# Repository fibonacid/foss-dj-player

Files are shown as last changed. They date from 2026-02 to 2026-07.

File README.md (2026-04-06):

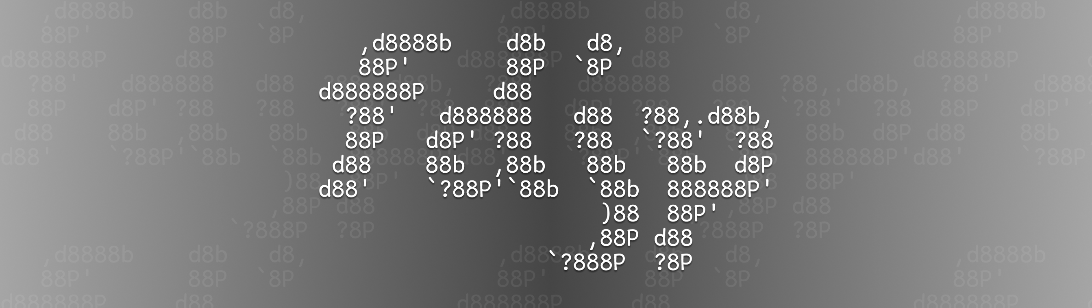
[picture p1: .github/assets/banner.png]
FOSS DJ PLAYER


<p align="center">
  <br/>
  DJ Players are over expensive and closed source. Let's fix it!
  <br/>
</p>

<div align="center">




</div>

Refer to the [docs](https://docs.foss-dj-player.org)

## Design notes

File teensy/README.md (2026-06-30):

# Firmware

## Sensor's list

So far we selected some sensors to tesst a possible layout of I/O we'd like to include. These are the sensors directly read by the teensy (few others directly interface with the raspberry pi).

- [ ] 1 1000PR jog wheel encoder [Exlimb E6B2-CWZ1X Incremental Rotary Encoder](https://it.aliexpress.com/item/1005006632253177.html).
- [ ] 1 track selection encoder [KY-040 360° rotary encoder module](https://it.aliexpress.com/item/1005010541982030.html)
- [x] 1 fader linear potentiometer [B10K 130 mm](https://it.aliexpress.com/item/1005006848969427.html)
- [x] buttons (16 buttons, pull-up resistor integrated into teensy)
    - 1 play
    - 1 cue
    - 5 hot cue
    - 1 master tempo
    - 3 loop (start, end, exit)
    - 1 fader scale
    - 2 next/prev track
    - 2 skip ahead/back
- [x] leds (3 leds)
    - 1 play
    - 1 cue
    - 2 loop active (to be integrated with loop start/end button)

## Libraries

- [bounce2](https://github.com/thomasfre) to implement automatic debouncing. 
- USBmidi is native and included in the .ini

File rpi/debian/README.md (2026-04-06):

# pi-gen

Tool used to create Raspberry Pi OS images, and custom images based on Raspberry Pi OS,
which was in turn derived from the Raspbian project.

**Note**: Raspberry Pi OS 32 bit images are based primarily on Raspbian, while
Raspberry Pi OS 64 bit images are based primarily on Debian.

**Note**: 32 bit images should be built from the `master` branch.
64 bit images should be built from the `arm64` branch.

## Dependencies

pi-gen runs on Debian-based operating systems released after 2017, and we
always advise you use the latest OS for security reasons.

On other Linux distributions it may be possible to use the Docker build described
below.

To install the required dependencies for `pi-gen` you should run:

```bash
apt install coreutils quilt parted qemu-user-static debootstrap zerofree zip \
dosfstools e2fsprogs libarchive-tools libcap2-bin grep rsync xz-utils file git curl bc \
gpg pigz xxd arch-test bmap-tools kmod
```

The file `depends` contains a list of tools needed. The format of this
package is `<tool>[:<debian-package>]`.

## Getting started with building your images

Getting started is as simple as cloning this repository on your build machine. You
can do so with:

```bash
git clone https://github.com/RPI-Distro/pi-gen.git
```

`--depth 1` can be added after `git clone` to create a shallow clone, only containing
the latest revision of the repository. Do not do this on your development machine.

Also, be careful to clone the repository to a base path **NOT** containing spaces.
This configuration is not supported by debootstrap and will lead to `pi-gen` not
running.

After cloning the repository, you can move to the next step and start configuring
your build.

## Config

Upon execution, `build.sh` will source the file `config` in the current
working directory. This bash shell fragment is intended to set needed
environment variables.

The following environment variables are supported:

- `IMG_NAME` (Default: `raspios-$RELEASE-$ARCH`, for example: `raspios-trixie-armhf`)

  The name of the image to build with the current stage directories. Use this
  variable to set the root name of your OS, eg `IMG_NAME=Frobulator`.
  Export files in stages may add suffixes to `IMG_NAME`.

- `PI_GEN_RELEASE` (Default: `Raspberry Pi reference`)

  The release name to use in `/etc/issue.txt`. The default should only be used
  for official Raspberry Pi builds.

- `RELEASE` (Default: `trixie`)

  The release version to build images against. Valid values are any supported
  Debian release. However, since different releases will have different sets of
  packages available, you'll need to either modify your stages accordingly, or
  checkout the appropriate branch. For example, if you'd like to build a
  `bullseye` image, you should do so from the `bullseye` branch.

- `APT_PROXY` (Default: unset)

  If you require the use of an apt proxy, set it here. This proxy setting
  will not be included in the image, making it safe to use an `apt-cacher` or
  similar package for development.

- `TEMP_REPO` (Default: unset)

  An additional temporary apt repo to be used during the build process. This
  could be useful if you require pre-release software to be included in the
  image. The variable should contain sources in [one-line-style format](https://manpages.debian.org/stable/apt/sources.list.5.en.html#ONE-LINE-STYLE_FORMAT).
  "RELEASE" will be replaced with the RELEASE variable.

- `BASE_DIR` (Default: location of `build.sh`)

  **CAUTION**: Currently, changing this value will probably break build.sh

  Top-level directory for `pi-gen`. Contains stage directories, build
  scripts, and by default both work and deployment directories.

- `WORK_DIR` (Default: `$BASE_DIR/work`)

  Directory in which `pi-gen` builds the target system. This value can be
  changed if you have a suitably large, fast storage location for stages to
  be built and cached. Note, `WORK_DIR` stores a complete copy of the target
  system for each build stage, amounting to tens of gigabytes in the case of
  Raspbian.

  **CAUTION**: If your working directory is on an NTFS partition you probably won't be able to build: make sure this is a proper Linux filesystem.

- `DEPLOY_DIR` (Default: `$BASE_DIR/deploy`)

  Output directory for target system images and NOOBS bundles.

- `DEPLOY_COMPRESSION` (Default: `zip`)

  Set to:
  - `none` to deploy the actual image (`.img`).
  - `zip` to deploy a zipped image (`.zip`).
  - `gz` to deploy a gzipped image (`.img.gz`).
  - `xz` to deploy a xzipped image (`.img.xz`).

- `DEPLOY_ZIP` (Deprecated)

  This option has been deprecated in favor of `DEPLOY_COMPRESSION`.

  If `DEPLOY_ZIP=0` is still present in your config file, the behavior is the
  same as with `DEPLOY_COMPRESSION=none`.

- `COMPRESSION_LEVEL` (Default: `6`)

  Compression level to be used when using `zip`, `gz` or `xz` for
  `DEPLOY_COMPRESSION`. From 0 to 9 (refer to the tool man page for more
  information on this. Usually 0 is no compression but very fast, up to 9 with
  the best compression but very slow ).

- `USE_QEMU` (Default: `0`)

  Setting to '1' enables the QEMU mode - creating an image that can be mounted via QEMU for an emulated
  environment. These images include "-qemu" in the image file name.

- `LOCALE_DEFAULT` (Default: 'en_GB.UTF-8' )

  Default system locale.

- `TARGET_HOSTNAME` (Default: 'raspberrypi' )

  Setting the hostname to the specified value.

- `KEYBOARD_KEYMAP` (Default: 'gb' )

  Default keyboard keymap.

  To get the current value from a running system, run `debconf-show
keyboard-configuration` and look at the
  `keyboard-configuration/xkb-keymap` value.

- `KEYBOARD_LAYOUT` (Default: 'English (UK)' )

  Default keyboard layout.

  To get the current value from a running system, run `debconf-show
keyboard-configuration` and look at the
  `keyboard-configuration/variant` value.

- `TIMEZONE_DEFAULT` (Default: 'Europe/London' )

  Default time zone.

  To get the current value from a running system, look in
  `/etc/timezone`.

- `FIRST_USER_NAME` (Default: `pi`)

  Username for the first user. This user only exists during the image creation process. Unless
  `DISABLE_FIRST_BOOT_USER_RENAME` is set to `1`, this user will be renamed on the first boot with
  a name chosen by the final user. This security feature is designed to prevent shipping images
  with a default username and help prevent malicious actors from taking over your devices.

  If the FIRST_USER_NAME is set to `pi` and no `FIRST_USER_PASS` is set, the setup wizard will be launched on first boot to allow the user to set the password.

- `FIRST_USER_PASS` (Default: unset)

  Password for the first user. If unset, the account is locked.

- `DISABLE_FIRST_BOOT_USER_RENAME` (Default: `0`)

  Disable the renaming of the first user during the first boot. This make it so `FIRST_USER_NAME`
  stays activated. `FIRST_USER_PASS` must be set for this to work. Please be aware of the implied
  security risk of defining a default username and password for your devices.

- `WPA_COUNTRY` (Default: unset)

  Sets the default WLAN regulatory domain and unblocks WLAN interfaces. This should be a 2-letter ISO/IEC 3166 country Code, i.e. `GB`

- `ENABLE_SSH` (Default: `0`)

  Setting to `1` will enable ssh server for remote log in. Note that if you are using a common password such as the defaults there is a high risk of attackers taking over you Raspberry Pi.

- `PUBKEY_SSH_FIRST_USER` (Default: unset)

Setting this to a value will make that value the contents of the FIRST_USER_NAME's ~/.ssh/authorized_keys. Obviously the value should
therefore be a valid authorized_keys file. Note that this does not
automatically enable SSH.

- `PUBKEY_ONLY_SSH` (Default: `0`)

- Setting to `1` will disable password authentication for SSH and enable
  public key authentication. Note that if SSH is not enabled this will take
  effect when SSH becomes enabled.

- `SETFCAP` (Default: unset)
  - Setting to `1` will prevent pi-gen from dropping the "capabilities"
    feature. Generating the root filesystem with capabilities enabled and running
    it from a filesystem that does not support capabilities (like NFS) can cause
    issues. Only enable this if you understand what it is.

- `STAGE_LIST` (Default: `stage*`)

  If set, then instead of working through the numeric stages in order, this list will be followed. For example setting to `"stage0 stage1 mystage stage2"` will run the contents of `mystage` before stage2. Note that quotes are needed around the list. An absolute or relative path can be given for stages outside the pi-gen directory.

- `EXPORT_CONFIG_DIR` (Default: `$BASE_DIR/export-image`)

  If set, use this directory path as the location of scripts to run when generating images. An absolute or relative path can be given for a location outside the pi-gen directory.

- `ENABLE_CLOUD_INIT` (Default: `1`)

  If set to `1`, cloud-init and netplan will be installed and configured. This will allow you to configure your Raspberry Pi using cloud-init configuration files. The cloud-init configuration files should be placed in the bootfs or by editing the files in `stage2/04-cloud-init/files`. Cloud-init will be configured to read them on first boot.

A simple example for building Raspberry Pi OS:

```bash
IMG_NAME='raspios'
```

The config file can also be specified on the command line as an argument the `build.sh` or `build-docker.sh` scripts.

```
./build.sh -c myconfig
```

This is parsed after `config` so can be used to override values set there.

## How the build process works

The following process is followed to build images:

- Iterate through all of the stage directories in alphanumeric order

- Bypass a stage directory if it contains a file called
  "SKIP"

- Run the script `prerun.sh` which is generally just used to copy the build
  directory between stages.

- In each stage directory iterate through each subdirectory and then run each of the
  install scripts it contains, again in alphanumeric order. **These need to be named
  with a two digit padded number at the beginning.**
  There are a number of different files and directories which can be used to
  control different parts of the build process:
  - **00-run.sh** - A unix shell script. Needs to be made executable for it to run.

  - **00-run-chroot.sh** - A unix shell script which will be run in the chroot
    of the image build directory. Needs to be made executable for it to run.

  - **00-debconf** - Contents of this file are passed to debconf-set-selections
    to configure things like locale, etc.

  - **00-packages** - A list of packages to install. Can have more than one, space
    separated, per line.

  - **00-packages-nr** - As 00-packages, except these will be installed using
    the `--no-install-recommends -y` parameters to apt-get.

  - **00-patches** - A directory containing patch files to be applied, using quilt.
    If a file named 'EDIT' is present in the directory, the build process will
    be interrupted with a bash session, allowing an opportunity to create/revise
    the patches.

- If the stage directory contains files called "EXPORT_NOOBS" or "EXPORT_IMAGE" then
  add this stage to a list of images to generate

- Generate the images for any stages that have specified them

It is recommended to examine build.sh for finer details.

## Docker Build

Docker can be used to perform the build inside a container. This partially isolates
the build from the host system, and allows using the script on non-debian based
systems (e.g. Fedora Linux). The isolation is not complete due to the need to use
some kernel level services for arm emulation (binfmt) and loop devices (losetup).

To build:

```bash
vi config         # Edit your config file. See above.
./build-docker.sh
```

If everything goes well, your finished image will be in the `deploy/` folder.
You can then remove the build container with `docker rm -v pigen_work`

If you encounter errors during the build, you can edit the corresponding scripts, and
continue:

```bash
CONTINUE=1 ./build-docker.sh
```

To examine the container after a failure you can enter a shell within it using:

```bash
sudo docker run -it --privileged --volumes-from=pigen_work pi-gen /bin/bash
```

After successful build, the build container is by default removed. This may be undesired when making incremental changes to a customized build. To prevent the build script from remove the container add

```bash
PRESERVE_CONTAINER=1 ./build-docker.sh
```

There is a possibility that even when running from a docker container, the
installation of `qemu-user-static` will silently fail when building the image
because `binfmt-support` _must be enabled on the underlying kernel_. An easy
fix is to ensure `binfmt-support` is installed on the host machine before
starting the `./build-docker.sh` script (or using your own docker build
solution).

### Passing arguments to Docker

When the docker image is run various required command line arguments are provided. For example the system mounts the `/dev` directory to the `/dev` directory within the docker container. If other arguments are required they may be specified in the PIGEN_DOCKER_OPTS environment variable. For example setting `PIGEN_DOCKER_OPTS="--add-host foo:192.168.0.23"` will add '192.168.0.23 foo' to the `/etc/hosts` file in the container. The `--name`
and `--privileged` options are already set by the script and should not be redefined.

## Stage Anatomy

### Raspbian Stage Overview

The build of Raspbian is divided up into several stages for logical clarity
and modularity. This causes some initial complexity, but it simplifies
maintenance and allows for more easy customization.

- **Stage 0** - bootstrap. The primary purpose of this stage is to create a
  usable filesystem. This is accomplished largely through the use of
  `debootstrap`, which creates a minimal filesystem suitable for use as a
  base.tgz on Debian systems. This stage also configures apt settings and
  installs `raspberrypi-bootloader` which is missed by debootstrap. The
  minimal core is installed but not configured. As a result, this stage will not boot.

- **Stage 1** - truly minimal system. This stage makes the system bootable by
  installing system files like `/etc/fstab`, configures the bootloader, makes
  the network operable, and installs packages like raspi-config. At this
  stage the system should boot to a local console from which you have the
  means to perform basic tasks needed to configure and install the system.

- **Stage 2** - lite system. This stage produces the Raspberry Pi OS Lite image.
  Stage 2 installs some optimized memory functions, sets timezone and charmap
  defaults, installs fake-hwclock and ntp, wireless LAN and bluetooth support,
  dphys-swapfile, and other basics for managing the hardware. It also
  creates necessary groups and gives the pi user access to sudo and the
  standard console hardware permission groups.

  Note: Raspberry Pi OS Lite contains a number of tools for development,
  including `Python`, `Lua` and the `build-essential` package. If you are
  creating an image to deploy in products, be sure to remove extraneous development
  tools before deployment.

- **Stage 3** - desktop system. Here's where you get the full desktop system
  with X11 and LXDE, web browsers, git for development, Raspberry Pi OS custom UI
  enhancements, etc. This is a base desktop system, with some development
  tools installed.

- **Stage 4** - Normal Raspberry Pi OS image. System meant to fit on a 4GB card.
  This is the stage that installs most things that make Raspberry Pi OS friendly
  to new users - e.g. system documentation.

- **Stage 5** - The Raspberry Pi OS Full image. More development
  tools, an email client, learning tools like Scratch, specialized packages
  like sonic-pi, office productivity, etc.

### Stage specification

If you wish to build up to a specified stage (such as building up to stage 2
for a lite system), place an empty file named `SKIP` in each of the `./stage`
directories you wish not to include.

Then add an empty file named `SKIP_IMAGES` to `./stage4` and `./stage5` (if building up to stage 2) or
to `./stage2` (if building a minimal system).

```bash
# Example for building a lite system
echo "IMG_NAME='raspios'" > config
touch ./stage3/SKIP ./stage4/SKIP ./stage5/SKIP
touch ./stage4/SKIP_IMAGES ./stage5/SKIP_IMAGES
sudo ./build.sh  # or ./build-docker.sh
```

If you wish to build further configurations upon (for example) the lite
system, you can also delete the contents of `./stage3` and `./stage4` and
replace with your own contents in the same format.

## Skipping stages to speed up development

If you're working on a specific stage the recommended development process is as
follows:

- Add a file called SKIP*IMAGES into the directories containing EXPORT*\* files
  (currently stage2, stage4 and stage5)
- Add SKIP files to the stages you don't want to build. For example, if you're
  basing your image on the lite image you would add these to stages 3, 4 and 5.
- Run build.sh to build all stages
- Add SKIP files to the earlier successfully built stages
- Modify the last stage
- Rebuild just the last stage using `sudo CLEAN=1 ./build.sh` (or, for docker builds
  `PRESERVE_CONTAINER=1 CONTINUE=1 CLEAN=1 ./build-docker.sh`)
- Once you're happy with the image you can remove the SKIP_IMAGES files and
  export your image to test

# Troubleshooting

## `64 Bit Systems`

A 64 bit image can be generated from the `arm64` branch in this repository. Just
replace the command from [this section](#getting-started-with-building-your-images)
by the one below, and follow the rest of the documentation:

```bash
git clone --branch arm64 https://github.com/RPI-Distro/pi-gen.git
```

If you want to generate a 64 bits image from a Raspberry Pi running a 32 bits
version, you need to add `arm_64bit=1` to your `config.txt` file and reboot your
machine. This will restart your machine with a 64 bits kernel. This will only
work from a Raspberry Pi with a 64-bit capable processor (i.e. Raspberry Pi Zero
2, Raspberry Pi 3 or Raspberry Pi 4).

## `binfmt_misc`

Linux is able to execute binaries from other architectures, meaning that it should be
possible to make use of `pi-gen` on an x86_64 system, even though it will be running
ARM binaries. This requires support from the [`binfmt_misc`](https://en.wikipedia.org/wiki/Binfmt_misc)
kernel module.

You may see one of the following errors:

```
update-binfmts: warning: Couldn't load the binfmt_misc module.
```

```
W: Failure trying to run: chroot "/pi-gen/work/test/stage0/rootfs" /bin/true
and/or
chroot: failed to run command '/bin/true': Exec format error
```

To resolve this, ensure that the following files are available (install them if necessary):

```
/lib/modules/$(uname -r)/kernel/fs/binfmt_misc.ko
/usr/bin/qemu-aarch64-static
```

You may also need to load the module by hand - run `modprobe binfmt_misc`.

If you are using WSL to build you may have to enable the service `sudo update-binfmts --enable`

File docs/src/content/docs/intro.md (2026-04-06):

---
title: Introduction
---

## Product requirements

- must be [standalone](#standalone)
- must be [cheap](#cheap)
- must be [easy to assemble](#easy-to-assemble)
- must be [compatible with rekordbox USB sticks](#compatible-with-rekordbox-usb-sticks)
- must be [dj software agnostic](#dj-software-agnostic)

### Standalone

The player embeds the software and hardware required for playback, instead of relying of software on a separate device/computer
In simple terms: it's a player not a controller.

### Cheap

Pioneer has a monopoly that allows it to charge ridiculus amounts of money. This project aims to make DJ players affordable for the average person.
A good price point would be around the cost of a entry level DJ controller or a bit more.
The price should not get too close to the entry level DJ player for Pioneer (XDJ-700) which costs around 700 euros.

### Easy to Assemble

The player must be simple enough for someone with basic electronics skills to assemble it in a few hours or so.
The electronics connections should be done with a custom PCB
The PCB should include slots for external modules like microcontrollers and periferals
Soldering should be required but fairly easy, not too many components

### Compatible with rekordbox USB sticks

The Pioneer monopoly forces you to use rekordbox to store your media, cues etc.
Sadly we cannot ditch completely the pioneer ecosystem without making the alternative feel like a toy.
Thankfully, [mixxx](https://github.com/mixxxdj/mixxx) already supports this.

### DJ Software agnostic

The cool part about open source DJ players is that you own it completely. This means you can decide what kind of software should run on the player.
This means that the hardware is not tied to any specific DJ software.
You can flash a micro SD card with a custom linux ISO, including the DJ software pre-configured with Midi mappings and UI skins for the embedded touchscreen.

## How does it work

The FOSS dj player is build of several parts, which can be ordered and assembled using the resources provided in this repo.

| Component | Notes |
| --- | --- |
| 3D printed case | to hold everything together |
| Custom PCB | to hold the electronic connections without running cables al over the place |
| Buttons, Faders, Jog Wheel etc. | to interact with the player |
| MIDI controller module | to expose sensor input to the dj software as MIDI |
| Raspberry PI | to host the operating system and dj software + peripherals (usb, ethernet) |
| Audio DAC module | to output good quality audio from the raspberry pi + RCA connector output for mixers |
| Touch Screen Display | to interact with the dj software, and control some aspects with touch |
| 3D printed inserts | stuff to cover buttons, encoders etc. |

## Help needed

This project requires help in the following fields:

- Electronics
  - Designing PCBs
  - Finding components
  - Testing and Prototyping
- Software
  - Embedded development
  - Linux Ricing (debian)
- Product
  - Research on features and pricing
  - Industrial Design for 3D printing

If you want to help out in any way or simply provide feedback/support, join the [discord server](https://discord.gg/WABteAtQdq)

## References

- [XDJ100SX](https://github.com/marcmonka/XDJ100SX) Primary inspiration for this project
- [MIXXX](https://github.com/mixxxdj/mixxx) A FOSS DJ Software compatible with Linux

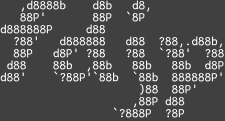
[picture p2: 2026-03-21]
design/brand/exports/fdjp/fdjp_dark_xs.png

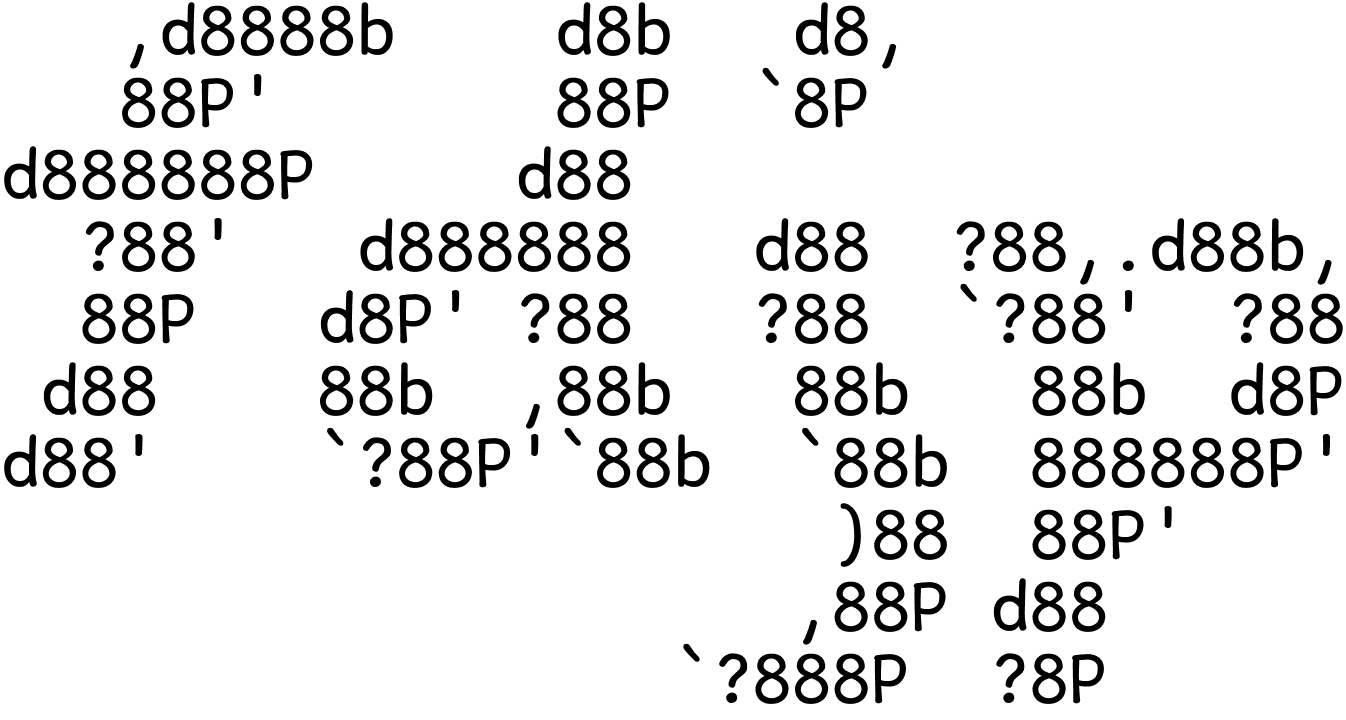
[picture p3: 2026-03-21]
design/brand/exports/fdjp/fdjp_light_7xl.png

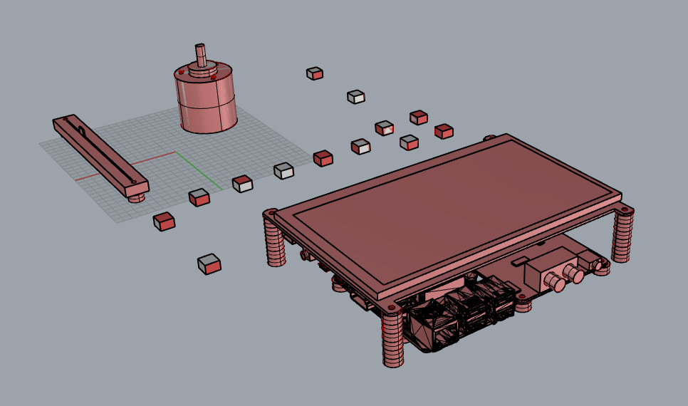
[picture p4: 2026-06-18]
design/cad/prototype-fede/ensemble.jpg

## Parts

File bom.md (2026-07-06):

# FOSS DJ Player — Bill of Materials

| ID  | Component | Manufacturer | Qty | Supplier | Notes |
| --- | --- | --- | --- | --- | --- |
| C1  | Rasperry PI 5 (RAM 8GB) | Raspberry Pi | 1 | [www.kubii.com](https://www.kubii.com/it/nano-computer/4106-raspberry-pi-5-3272496315938.html) (SKU: PI5) | 4GB version might work too |
| C2  | Power Supply Raspberry Pi USB-C 45W | | | [www.kubii.com](https://www.kubii.com/it/alimentatori/4658-2379-alimentazione-raspberry-pi-usb-c-45w-3272496323698.html) (SKU: PS-45W) | |
| C3  | DAC Audio IQaudio for Raspberry Pi (DAC+) | Raspberry Pi | 1 | [www.kubii.com](https://www.kubii.com/it/hat-dac-moduli/3181-dac-audio-iqaudio-per-raspberry-pi-3272496311565.html) | |
| C4  | Micro-SD Card (64 GB)" | Verbatim | | [www.kubii.com](https://www.kubii.com/it/supporti-di-archiviazione/3061-1479-scheda-micro-sd-verbatim-classe-10-3272496311527.html) (SKU: 44087_DEL) | |
| C5  | 7-inch capacitive LCD touch screen for Raspberry Pi | Waveshare | | [www.kubii.com](https://www.kubii.com/en/displays-supports/3789-7-inch-capacitive-lcd-touch-screen-for-raspberry-3272496312562.html) (SKU: WV14628)  | |
| C6  | Cooling fan for Raspberry Pi 5 | Rasberry Pi  | | [www.kubii.com](https://www.kubii.com/en/fans-heat-sinks/4109-cooling-fan-for-raspberry-pi-5-5056561803357.html) (SKU: SC1148) | |
| C7  | GPIO cable for Raspberry Pi | Kubii | | [www.kubii.com](https://www.kubii.com/en/hub-cables-adapters/426-gpio-cable-for-raspberry-pi-3272496001350.html) (SKU: KUB1988) | |
| E1  | Teensy 4.1 | PJRC | | [www.sparkfun.com](https://www.sparkfun.com/teensy-4-1-without-ethernet.html) (SKU: DEV-20359) | |

_Total components: 8_

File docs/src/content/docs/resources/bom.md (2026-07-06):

---
title: Bill of Materials
---

| ID  | Component | Manufacturer | Qty | Supplier | Notes |
| --- | --- | --- | --- | --- | --- |
| C1  | Rasperry PI 5 (RAM 8GB) | Raspberry Pi | 1 | [www.kubii.com](https://www.kubii.com/it/nano-computer/4106-raspberry-pi-5-3272496315938.html) (SKU: PI5) | 4GB version might work too |
| C2  | Power Supply Raspberry Pi USB-C 45W | Raspberry Pi | 1 | [www.kubii.com](https://www.kubii.com/it/alimentatori/4658-2379-alimentazione-raspberry-pi-usb-c-45w-3272496323698.html) (SKU: PS-45W) | |
| C3  | DAC Audio IQaudio for Raspberry Pi (DAC+) | Raspberry Pi | 1 | [www.kubii.com](https://www.kubii.com/it/hat-dac-moduli/3181-dac-audio-iqaudio-per-raspberry-pi-3272496311565.html) | |
| C4  | Micro-SD Card (64 GB)" | Verbatim | 1 | [www.kubii.com](https://www.kubii.com/it/supporti-di-archiviazione/3061-1479-scheda-micro-sd-verbatim-classe-10-3272496311527.html) (SKU: 44087_DEL) | |
| C5  | 7-inch capacitive LCD touch screen for Raspberry Pi | Waveshare | 1 | [www.kubii.com](https://www.kubii.com/en/displays-supports/3789-7-inch-capacitive-lcd-touch-screen-for-raspberry-3272496312562.html) (SKU: WV14628)  | |
| C6  | Cooling fan for Raspberry Pi 5 | Rasberry Pi  | 1 | [www.kubii.com](https://www.kubii.com/en/fans-heat-sinks/4109-cooling-fan-for-raspberry-pi-5-5056561803357.html) (SKU: SC1148) | |
| C7  | GPIO cable for Raspberry Pi | Kubii | 1 | [www.kubii.com](https://www.kubii.com/en/hub-cables-adapters/426-gpio-cable-for-raspberry-pi-3272496001350.html) (SKU: KUB1988) | |
| E1  | Teensy 4.1 | PJRC | 1 | [www.sparkfun.com](https://www.sparkfun.com/teensy-4-1-without-ethernet.html) (SKU: DEV-20359) | |

_Total components: 8_

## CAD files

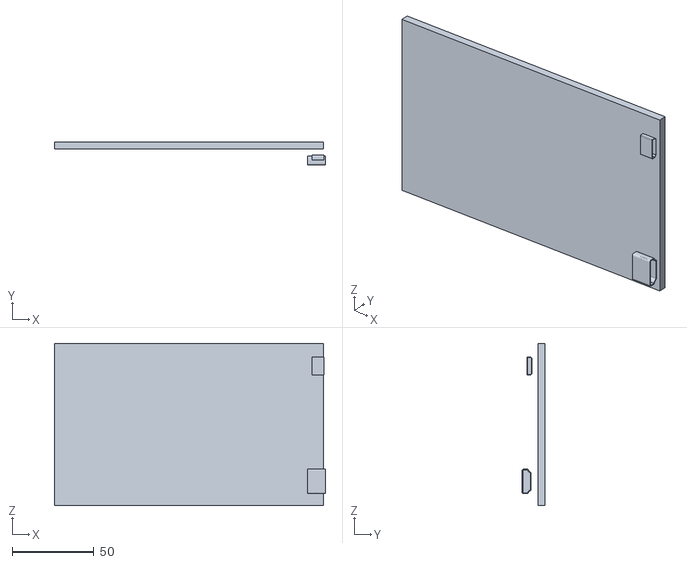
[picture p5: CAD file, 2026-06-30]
design/cad/_assets-digital-twins/lcd_panel.obj
165.4 x 14.0 x 99.0

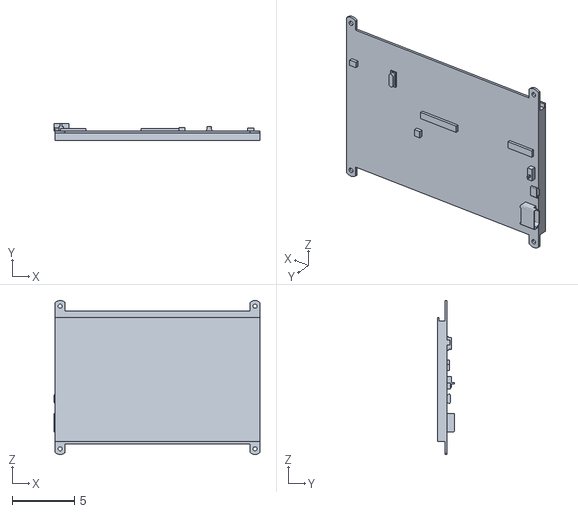
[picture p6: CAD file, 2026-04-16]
design/cad/_assets-generic/7inch_HDMI_LCD.obj
16.6 x 1.41 x 12.4

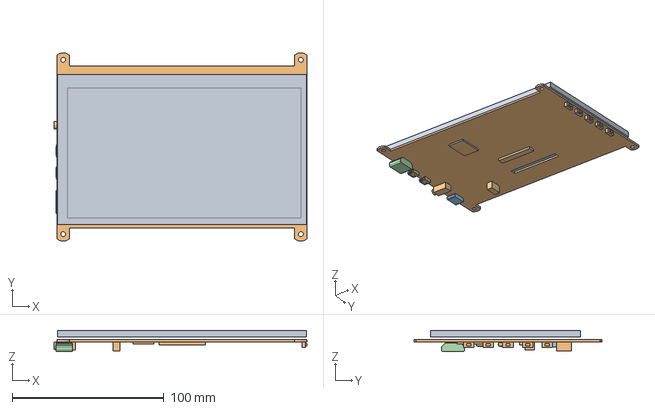
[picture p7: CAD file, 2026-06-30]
design/cad/_assets-generic/7inch_HDMI_LCD_(H)_drawing/f16-2.stp
167.0 x 124.3 x 14.0 mm

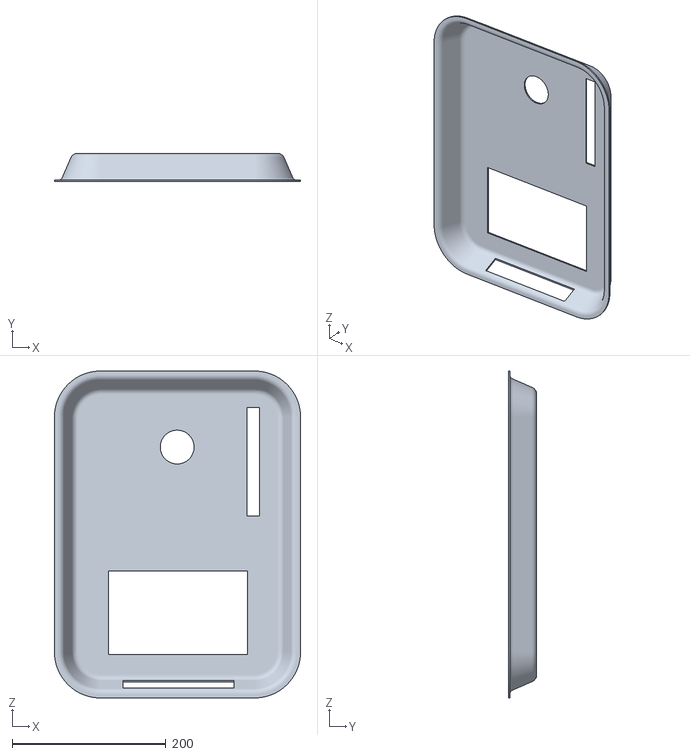
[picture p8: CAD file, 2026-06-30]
design/cad/_prototype/chassis.obj
320.0 x 37.0 x 425.0

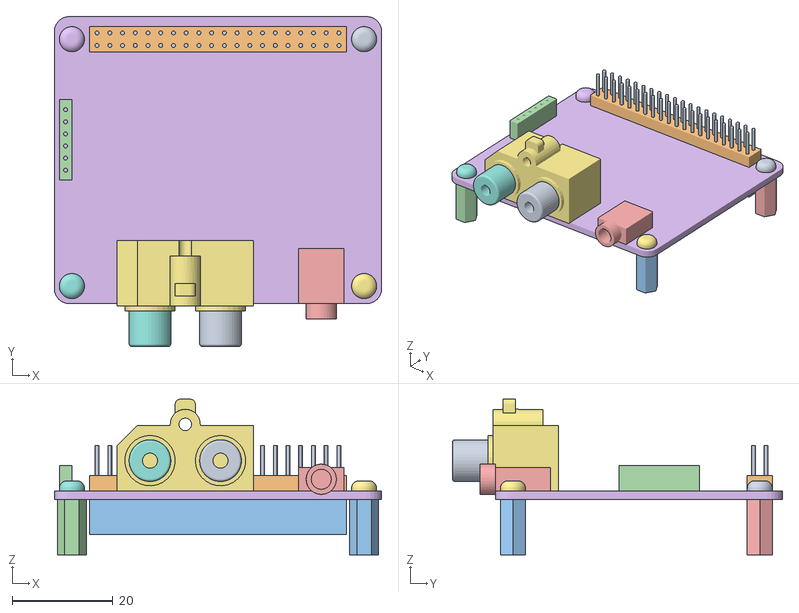
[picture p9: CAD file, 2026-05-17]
design/cad/dac.obj
65.0 x 65.5 x 30.9
Pins
Base
GPIO Socket
XLR Header
PCB

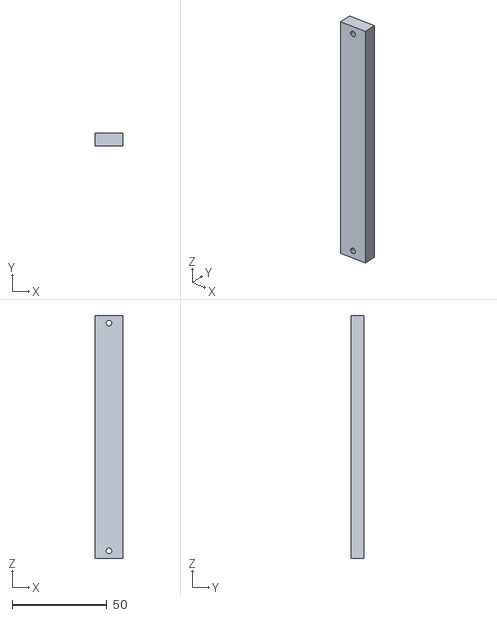
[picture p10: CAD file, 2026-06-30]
design/cad/_assets-digital-twins/potenziometro.obj
15.0 x 7.00 x 128.0

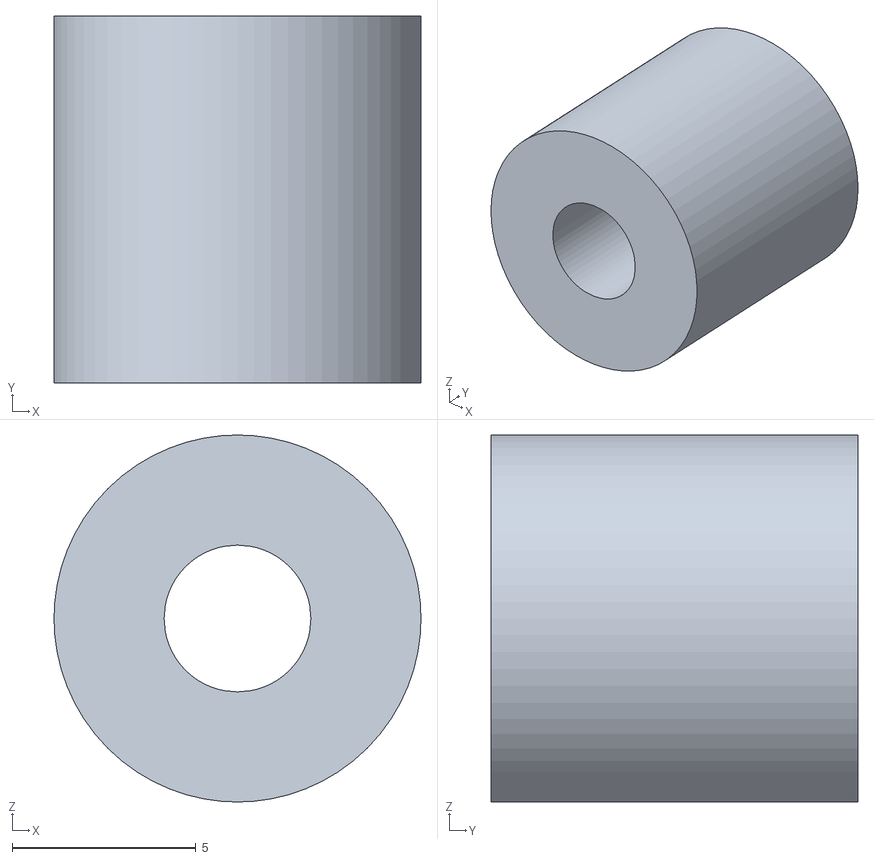
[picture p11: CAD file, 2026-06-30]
design/cad/_prototype/spacer.obj
10.0 x 10.0 x 10.0

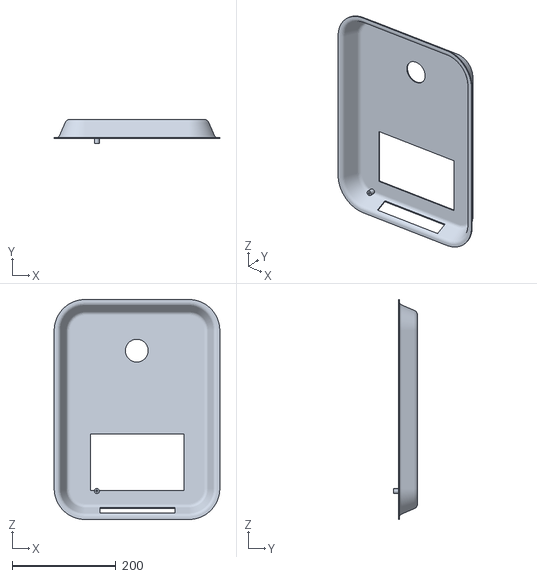
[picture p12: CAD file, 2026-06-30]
design/cad/_assets-digital-twins/spacer.obj
320.0 x 47.0 x 425.0

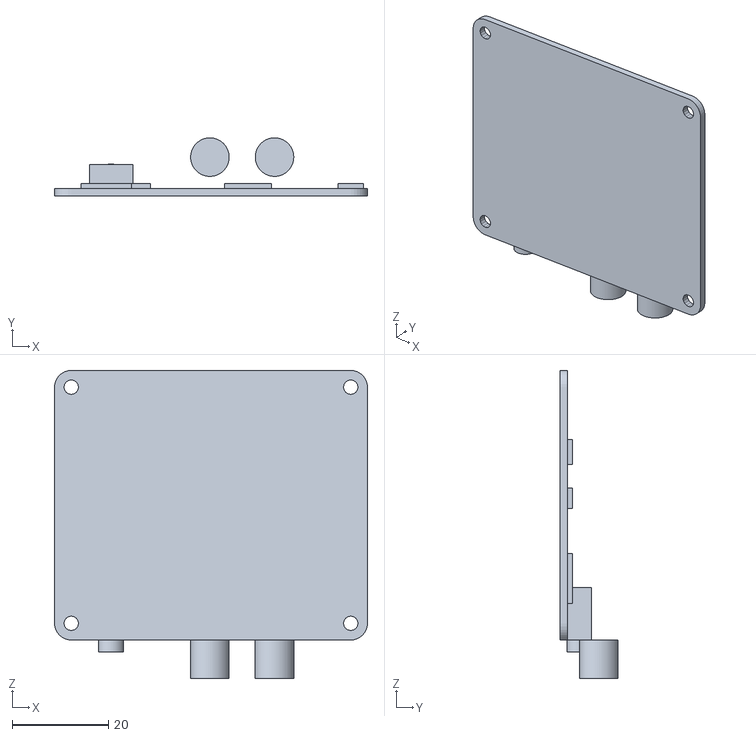
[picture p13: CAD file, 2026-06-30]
design/cad/_assets-digital-twins/pi_dac.obj
65.0 x 12.1 x 64.0

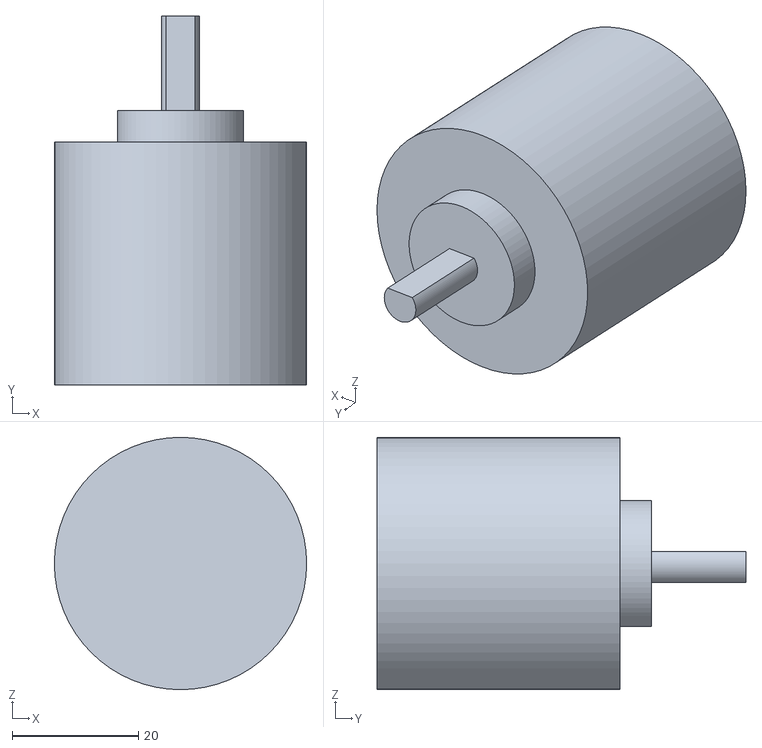
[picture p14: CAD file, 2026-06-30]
design/cad/_assets-digital-twins/rotary-encoder.obj
40.0 x 58.5 x 40.0

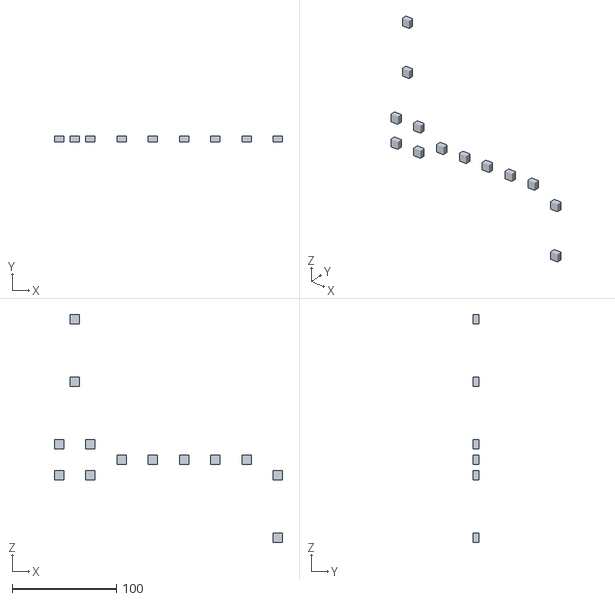
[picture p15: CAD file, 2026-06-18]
design/cad/_assets-digital-twins/buttons+enclosures.obj
219.0 x 6.00 x 219.0

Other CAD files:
design/cad/_assets-digital-twins/chassis.obj
design/cad/_assets-generic/7inch_HDMI_LCD_(H)_drawing/f16-2.dwg

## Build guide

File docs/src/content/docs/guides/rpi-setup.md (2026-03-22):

---
title: RPI Setup
description: Guide to prepare a Raspberry Pi with fdjp os image
---

## Prerequisites

### Hardware

- 1 Raspberry Pi 5 (8 gb recommended)
- 1 Waveshare 7 inch touch display
- 1 Raspberry Pi DAC Pro/+ Hat
- 1 microSD Card
- 1 GPIO ribbon cable

### Software

- Balena Etcher

## Preparing SD Card

Go to the [Releases](https://github.com/fibonacid/foss-dj-player/releases) page and scroll down until you see the _Assets_ list.
Click on the link for `foss-dj-player.zip` to download the disk image.
Open _Balena Etcher_ and insert microSD card into your computer to flash it with the file you just downloaded.
After flashing is done, remove the microSD card from your computer and put it in the Raspberry Pi.
When you turn on the RPI, you should expect the following:

1. splash screen with fjdp logo
2. tty screen with fdjp logo
3. mixxx opens automatically at fullscreen

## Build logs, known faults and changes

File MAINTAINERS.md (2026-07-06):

# Maintainers

This doc is for maintainers of this repo

## Node.js

Some aspect of the codebase are administered with Node.js.
To use node, the recommended approach is to download and install [nvm](https://github.com/nvm-sh/nvm)
After installing nvm, open a terminal in the repository root and run:

```bash
nvm use
corepack enable
corepack up
pnpm install
```

If everything is ok you can now run commands like these:

```bash
pnpm format
```

## Python

The script folder contains several python files that should be run with [uv](https://docs.astral.sh/uv/getting-started/installation/#standalone-installer)

```bash
# generate bom and put into public docs
pnpm scripts:bom
```

## Docker

To build RPI images we use docker. Install a recent version and refer to the `rpi` folder for details.

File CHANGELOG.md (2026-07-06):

# Changelog

## [0.1.6](https://github.com/fibonacid/foss-dj-player/compare/0.1.5...0.1.6) (2026-07-06)

### Bug Fixes

* **mixxx-controller:** add missing dev deps ([374c467](https://github.com/fibonacid/foss-dj-player/commit/374c46766ab9164773d413afb36cb1e53d61323b))
* **mixxx-controller:** correct controller class name ([8173c9d](https://github.com/fibonacid/foss-dj-player/commit/8173c9d597c72bdfcf93cf380559f0d67ad9180b))
* **mixxx-controller:** pin node and pnpm version ([bde6560](https://github.com/fibonacid/foss-dj-player/commit/bde656042b5d30fd3d20c4f422ca6224b974487e))

### Features

* **design:** add prototype cad files ([#31](https://github.com/fibonacid/foss-dj-player/issues/31)) ([54a9fd1](https://github.com/fibonacid/foss-dj-player/commit/54a9fd162045ca6d5f46cb2c5017688a25e04d49))
* **design:** modify foss-dj-player Grasshopper prototype ([#32](https://github.com/fibonacid/foss-dj-player/issues/32)) ([959edf2](https://github.com/fibonacid/foss-dj-player/commit/959edf2038ca3964d03e1f47ee02b83608ebf0ba))
* **firmware:** initial draft ([#30](https://github.com/fibonacid/foss-dj-player/issues/30)) ([fe4329b](https://github.com/fibonacid/foss-dj-player/commit/fe4329b4bfdf0a027fb77f74c9ce039c6e130e18))

## [0.1.5](https://github.com/fibonacid/foss-dj-player/compare/0.1.4...0.1.5) (2026-04-19)

### Features

* **alpine:** create alpine based rpi image ([#23](https://github.com/fibonacid/foss-dj-player/issues/23)) ([c0a0f6e](https://github.com/fibonacid/foss-dj-player/commit/c0a0f6e3263a293bda0a85c8ea99c6ba9b9d625e))
* **alpine:** export alpine img as zip ([a04e015](https://github.com/fibonacid/foss-dj-player/commit/a04e015954c5bd886dbe0de083595bb2d02cb2b9))
* **design:** export obj files from autodesk ([#24](https://github.com/fibonacid/foss-dj-player/issues/24)) ([541460f](https://github.com/fibonacid/foss-dj-player/commit/541460f5e53606a461512975381b36a2203a377f))
* **extra:** create mixxx controller xml and script ([#25](https://github.com/fibonacid/foss-dj-player/issues/25)) ([3c110b7](https://github.com/fibonacid/foss-dj-player/commit/3c110b7b21e6c93473bafef6a976ec9e4b0f53ab))
* **mixxx-controller:** add loop adjust mapping ([#27](https://github.com/fibonacid/foss-dj-player/issues/27)) ([859f768](https://github.com/fibonacid/foss-dj-player/commit/859f768139df5169981ef9a24c359677ffc3f3f9))

## [0.1.4](https://github.com/fibonacid/foss-dj-player/compare/0.1.3...0.1.4) (2026-04-06)

## [0.1.3](https://github.com/fibonacid/foss-dj-player/compare/0.1.2...0.1.3) (2026-03-22)

## [0.1.1](https://github.com/fibonacid/foss-dj-player/compare/0.1.0...0.1.1) (2026-03-08)

### Features

* **pi-gen:** add bootsplash image ([#13](https://github.com/fibonacid/foss-dj-player/issues/13)) ([14ae84f](https://github.com/fibonacid/foss-dj-player/commit/14ae84fec0b247044cb37747952364b43a7ae5f4))

# 0.1.0 (2026-02-28)

### Bug Fixes

* **pi-gen:** error in chown command ([b02b36c](https://github.com/fibonacid/foss-dj-player/commit/b02b36c7427b78380637a8bf087d7eba14a7ae9b))

### Features

* **pi-gen:** add autologin ([#3](https://github.com/fibonacid/foss-dj-player/issues/3)) ([99290bf](https://github.com/fibonacid/foss-dj-player/commit/99290bf9f07f665108c88a2e2c99f9eba583a153))
* **pi-gen:** add XDJ100SX skin ([14854aa](https://github.com/fibonacid/foss-dj-player/commit/14854aa2643efcf590b68af2a94f961a044e07e8))
* **pi-gen:** auto mount usb ([#2](https://github.com/fibonacid/foss-dj-player/issues/2)) ([15296db](https://github.com/fibonacid/foss-dj-player/commit/15296db7cc5e4931a4a36858f7f485b1994a2844))
* **pi-gen:** disable other libraries than rekordbox ([7b709c1](https://github.com/fibonacid/foss-dj-player/commit/7b709c1eccb8accb1d298b8e22e17e88fba4772e))
* **pi-gen:** seed mixxx config with XDJ100SX ([6151d7b](https://github.com/fibonacid/foss-dj-player/commit/6151d7b8c739be0abf23bc165696c4a49ad41eda))
* **pi-gen:** setup pi-gen ([5fe8b43](https://github.com/fibonacid/foss-dj-player/commit/5fe8b43f261de78647b036b66db9df736ae27f66))
* **pi-gen:** tiling window manager ([#4](https://github.com/fibonacid/foss-dj-player/issues/4)) ([a386c17](https://github.com/fibonacid/foss-dj-player/commit/a386c17458100540d397f9775a66ff7cb42af708))

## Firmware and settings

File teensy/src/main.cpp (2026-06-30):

#include <Arduino.h>
#include <Bounce2.h>
#include <Encoder.h>
#include "config.h"

Bounce butts[buttons::NUM_BUTTONS];
Encoder browse_enc(browse_encoder::BROWSE_ENC_A, browse_encoder::BROWSE_ENC_B);
Encoder jog(jogwheel::JOG_PIN_A, jogwheel::JOG_PIN_B);
Bounce browse_button = Bounce();
int last_fader = -1;
long old_jog_pos = 0;
unsigned long last_midi_time = 0;
const int update_interval = 10; // jogwheel update time in ms not to fill the buffer


// functions to handle leds
void note_on(byte channel, byte note, byte velocity) {
    for (int i = 0; i < leds::NUM_LEDS; i++) {
        if (note == leds::LED_NOTES[i]) {
            digitalWrite(leds::LED_PINS[i], velocity > 0 ? HIGH : LOW);
        }
    }
}

void note_off(byte channel, byte note, byte velocity) {
    for (int i = 0; i < leds::NUM_LEDS; i++) {
        if (note == leds::LED_NOTES[i]) {
            digitalWrite(leds::LED_PINS[i], LOW);
        }
    }
}



void setup() {

    // buttons
    for (int i = 0; i < buttons::NUM_BUTTONS; i++) {
        butts[i].attach(buttons::BUTTON_PINS[i], INPUT_PULLUP);
        butts[i].interval(buttons::DEBOUNCE_MS);
    }    

    // leds
    for (int i = 0; i < leds::NUM_LEDS; i++) {
        pinMode(leds::LED_PINS[i], OUTPUT); 
    }


    // browse encoder
    browse_button.attach(browse_encoder::BROWSE_BTN, INPUT_PULLUP);
    browse_button.interval(5);

    // callback for leds
    usbMIDI.setHandleNoteOn(note_on);
    usbMIDI.setHandleNoteOff(note_on);

}

void loop() {
    
    // read led event
    while (usbMIDI.read()) {}

    // buttons
    for (int i = 0; i < buttons::NUM_BUTTONS; i++) {    
        
        butts[i].update();
        
        if(butts[i].fell()) {
            usbMIDI.sendNoteOn(midi_config::NOTES[i], 127, midi_config::BUTTON_CHANNEL);
        }

        if(butts[i].rose()) {
            usbMIDI.sendNoteOff(midi_config::NOTES[i], 0, midi_config::BUTTON_CHANNEL);
        }

    }

    // fader
    int curr_fader = analogRead(fader::PIN) >> 3; // filter by cutting down 3 bits to 7 (128 pos)
    if (abs(curr_fader - last_fader) > fader::THRESH) { 
        usbMIDI.sendControlChange(midi_config::FADER_CC, curr_fader, 1);
        last_fader = curr_fader;
    }


    // browse encoder (rotation)
    static long oldBrowsePos = 0;
    long newBrowsePos = browse_enc.read() >> 2; // divide by 4 
    if (newBrowsePos != oldBrowsePos) {
        int delta = (newBrowsePos > oldBrowsePos) ? 65 : 63;
        usbMIDI.sendControlChange(browse_encoder::BROWSE_CC, delta, 1);
        oldBrowsePos = newBrowsePos;
    }

    // browse encoder (load track button)
    browse_button.update();
    if (browse_button.fell()) usbMIDI.sendNoteOn(browse_encoder::BROWSE_LOAD_NOTE, 127, 1);
    if (browse_button.rose()) usbMIDI.sendNoteOff(browse_encoder::BROWSE_LOAD_NOTE, 0, 1);

    // jogwheel encoder
    long new_jog_pos = jog.read();

    if (millis() - last_midi_time > update_interval) {
        if (new_jog_pos != old_jog_pos) {
            long diff = new_jog_pos - old_jog_pos;

            // 64 is 0. >64 forward, <64 backwards
            int delta;
            if (diff > 0) {
                delta = 64 + min((long)63, diff); // limit max jump
            } 
            else {
                delta = 64 - min((long)64, abs(diff));
            }

            usbMIDI.sendControlChange(jogwheel::JOG_CC, delta, jogwheel::MIDI_CH);
            
            old_jog_pos = new_jog_pos;
            last_midi_time = millis();
        }
    }



}

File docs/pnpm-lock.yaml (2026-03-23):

lockfileVersion: '9.0'

settings:
  autoInstallPeers: true
  excludeLinksFromLockfile: false

importers:

  .:
    dependencies:
      '@astrojs/starlight':
        specifier: ^0.38.1
        version: 0.38.1(astro@6.0.4(@types/node@24.12.0)(rollup@4.59.0))
      astro:
        specifier: ^6.0.1
        version: 6.0.4(@types/node@24.12.0)(rollup@4.59.0)
      astro-og-canvas:
        specifier: ^0.10.1
        version: 0.10.1(astro@6.0.4(@types/node@24.12.0)(rollup@4.59.0))
      canvaskit-wasm:
        specifier: ^0.41.0
        version: 0.41.0
      sharp:
        specifier: ^0.34.2
        version: 0.34.5

packages:

  '@astrojs/compiler@3.0.0':
    resolution: {integrity: sha512-MwAbDE5mawZ1SS+D8qWiHdprdME5Tlj2e0YjxnEICvcOpbSukNS7Sa7hA5PK+6RrmUr/t6Gi5YgrdZKjbO/WPQ==}

  '@astrojs/internal-helpers@0.8.0':
    resolution: {integrity: sha512-J56GrhEiV+4dmrGLPNOl2pZjpHXAndWVyiVDYGDuw6MWKpBSEMLdFxHzeM/6sqaknw9M+HFfHZAcvi3OfT3D/w==}

  '@astrojs/markdown-remark@7.0.0':
    resolution: {integrity: sha512-jTAXHPy45L7o1ljH4jYV+ShtOHtyQUa1mGp3a5fJp1soX8lInuTJQ6ihmldHzVM4Q7QptU4SzIDIcKbBJO7sXQ==}

  '@astrojs/mdx@5.0.0':
    resolution: {integrity: sha512-J4rW6eT+qgVw7+RXdBYO4vYyWGeXXQp8wop9dXsOlLzIsVSxyttMCgkGCWvIR2ogBqKqeYgI6YDW93PaDHkCaA==}
    engines: {node: ^20.19.1 || >=22.12.0}
    peerDependencies:
      astro: ^6.0.0-alpha.0

  '@astrojs/prism@4.0.0':
    resolution: {integrity: sha512-NndtNPpxaGinRpRytljGBvYHpTOwHycSZ/c+lQi5cHvkqqrHKWdkPEhImlODBNmbuB+vyQUNUDXyjzt66CihJg==}
    engines: {node: ^20.19.1 || >=22.12.0}

  '@astrojs/sitemap@3.7.1':
    resolution: {integrity: sha512-IzQqdTeskaMX+QDZCzMuJIp8A8C1vgzMBp/NmHNnadepHYNHcxQdGLQZYfkbd2EbRXUfOS+UDIKx8sKg0oWVdw==}

  '@astrojs/starlight@0.38.1':
    resolution: {integrity: sha512-CATPH4Dy44OYAJhoyUHh6NqpColWEVufanGVwnM0l/bcaNMo5V/rypwL0Vu0Edp+ZIXE7/1DA9CrNj5jmCVSLQ==}
    peerDependencies:
      astro: ^6.0.0

  '@astrojs/telemetry@3.3.0':
    resolution: {integrity: sha512-UFBgfeldP06qu6khs/yY+q1cDAaArM2/7AEIqQ9Cuvf7B1hNLq0xDrZkct+QoIGyjq56y8IaE2I3CTvG99mlhQ==}
    engines: {node: 18.20.8 || ^20.3.0 || >=22.0.0}

  '@babel/helper-string-parser@7.27.1':
    resolution: {integrity: sha512-qMlSxKbpRlAridDExk92nSobyDdpPijUq2DW6oDnUqd0iOGxmQjyqhMIihI9+zv4LPyZdRje2cavWPbCbWm3eA==}
    engines: {node: '>=6.9.0'}

  '@babel/helper-validator-identifier@7.28.5':
    resolution: {integrity: sha512-qSs4ifwzKJSV39ucNjsvc6WVHs6b7S03sOh2OcHF9UHfVPqWWALUsNUVzhSBiItjRZoLHx7nIarVjqKVusUZ1Q==}
    engines: {node: '>=6.9.0'}

  '@babel/parser@7.29.0':
    resolution: {integrity: sha512-IyDgFV5GeDUVX4YdF/3CPULtVGSXXMLh1xVIgdCgxApktqnQV0r7/8Nqthg+8YLGaAtdyIlo2qIdZrbCv4+7ww==}
    engines: {node: '>=6.0.0'}
    hasBin: true

  '@babel/runtime@7.28.6':
    resolution: {integrity: sha512-05WQkdpL9COIMz4LjTxGpPNCdlpyimKppYNoJ5Di5EUObifl8t4tuLuUBBZEpoLYOmfvIWrsp9fCl0HoPRVTdA==}
    engines: {node: '>=6.9.0'}

  '@babel/types@7.29.0':
    resolution: {integrity: sha512-LwdZHpScM4Qz8Xw2iKSzS+cfglZzJGvofQICy7W7v4caru4EaAmyUuO6BGrbyQ2mYV11W0U8j5mBhd14dd3B0A==}
    engines: {node: '>=6.9.0'}

  '@capsizecss/unpack@4.0.0':
    resolution: {integrity: sha512-VERIM64vtTP1C4mxQ5thVT9fK0apjPFobqybMtA1UdUujWka24ERHbRHFGmpbbhp73MhV+KSsHQH9C6uOTdEQA==}
    engines: {node: '>=18'}

  '@clack/core@1.1.0':
    resolution: {integrity: sha512-SVcm4Dqm2ukn64/8Gub2wnlA5nS2iWJyCkdNHcvNHPIeBTGojpdJ+9cZKwLfmqy7irD4N5qLteSilJlE0WLAtA==}

  '@clack/prompts@1.1.0':
    resolution: {integrity: sha512-pkqbPGtohJAvm4Dphs2M8xE29ggupihHdy1x84HNojZuMtFsHiUlRvqD24tM2+XmI+61LlfNceM3Wr7U5QES5g==}

  '@ctrl/tinycolor@4.2.0':
    resolution: {integrity: sha512-kzyuwOAQnXJNLS9PSyrk0CWk35nWJW/zl/6KvnTBMFK65gm7U1/Z5BqjxeapjZCIhQcM/DsrEmcbRwDyXyXK4A==}
    engines: {node: '>=14'}

  '@emnapi/runtime@1.9.0':
    resolution: {integrity: sha512-QN75eB0IH2ywSpRpNddCRfQIhmJYBCJ1x5Lb3IscKAL8bMnVAKnRg8dCoXbHzVLLH7P38N2Z3mtulB7W0J0FKw==}

  '@esbuild/aix-ppc64@0.27.4':
    resolution: {integrity: sha512-cQPwL2mp2nSmHHJlCyoXgHGhbEPMrEEU5xhkcy3Hs/O7nGZqEpZ2sUtLaL9MORLtDfRvVl2/3PAuEkYZH0Ty8Q==}
    engines: {node: '>=18'}
    cpu: [ppc64]
    os: [aix]

  '@esbuild/android-arm64@0.27.4':
    resolution: {integrity: sha512-gdLscB7v75wRfu7QSm/zg6Rx29VLdy9eTr2t44sfTW7CxwAtQghZ4ZnqHk3/ogz7xao0QAgrkradbBzcqFPasw==}
    engines: {node: '>=18'}
    cpu: [arm64]
    os: [android]

  '@esbuild/android-arm@0.27.4':
    resolution: {integrity: sha512-X9bUgvxiC8CHAGKYufLIHGXPJWnr0OCdR0anD2e21vdvgCI8lIfqFbnoeOz7lBjdrAGUhqLZLcQo6MLhTO2DKQ==}
    engines: {node: '>=18'}
    cpu: [arm]
    os: [android]

  '@esbuild/android-x64@0.27.4':
    resolution: {integrity: sha512-PzPFnBNVF292sfpfhiyiXCGSn9HZg5BcAz+ivBuSsl6Rk4ga1oEXAamhOXRFyMcjwr2DVtm40G65N3GLeH1Lvw==}
    engines: {node: '>=18'}
    cpu: [x64]
    os: [android]

  '@esbuild/darwin-arm64@0.27.4':
    resolution: {integrity: sha512-b7xaGIwdJlht8ZFCvMkpDN6uiSmnxxK56N2GDTMYPr2/gzvfdQN8rTfBsvVKmIVY/X7EM+/hJKEIbbHs9oA4tQ==}
    engines: {node: '>=18'}
    cpu: [arm64]
    os: [darwin]
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

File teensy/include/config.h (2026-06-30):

#ifndef CONFIG_H
#define CONFIG_H
#include <Arduino.h>


// ----- pins -----

namespace buttons {
    
    constexpr int NUM_BUTTONS   = 16; 
    constexpr int BUTTON_PINS[NUM_BUTTONS] = {0, 1, 2, 3, 4, 5, 6, 7, 8, 9, 10, 11, 12, 15, 16, 17};
    constexpr int DEBOUNCE_MS = 5;
    
    // constexpr int PLAY          = 0; 
    // constexpr int CUE           = 1;
    // constexpr int HOT_CUE       = 2;
    // constexpr int HOT_CUE       = 3;
    // constexpr int HOT_CUE       = 4;
    // constexpr int HOT_CUE       = 5;
    // constexpr int HOT_CUE       = 6;
    // constexpr int MASTER_TEMPO  = 7;
    // constexpr int LOOP_START    = 8;
    // constexpr int LOOP_END      = 9;
    // constexpr int LOOP_EXIT     = 10;
    // constexpr int FADER_SCALE   = 11;
    // constexpr int NEXT_TRACK    = 12;
    // constexpr int PREV_TRACK    = 15; // 14 is A0
    // constexpr int SKIP_AHEAD    = 16;
    // constexpr int SKIP_BACK     = 17;    
} 

namespace leds {

    constexpr int NUM_LEDS = 4;
    constexpr int LED_PINS[NUM_LEDS] = {0, 1, 4, 5}; 
    constexpr int LED_NOTES[NUM_LEDS] = {60, 61, 64, 65}; 

} 

namespace fader {

    constexpr int PIN = A0;
    constexpr int THRESH = 5; 

} 

namespace browse_encoder {
    
    constexpr int BROWSE_ENC_A = 26;
    constexpr int BROWSE_ENC_B = 27;
    constexpr int BROWSE_BTN = 28;    
    constexpr int BROWSE_CC = 12;     
    constexpr int BROWSE_LOAD_NOTE = 75;

}

namespace jogwheel {
    // pins for the encoder (E6B2-CWZ1X)
    constexpr int JOG_PIN_A = 24; 
    constexpr int JOG_PIN_B = 25;
    
    constexpr int JOG_CC = 11;
    constexpr int MIDI_CH = 1;
}

// ----- MIDI config -----

namespace midi_config {
    constexpr int NOTES[buttons::NUM_BUTTONS] = {60, 61, 62, 63, 64, 65, 70, 71, 72, 73, 74, 75};    // to be mapped from note to play, cue, etc
    constexpr int BUTTON_CHANNEL = 1;
    constexpr int FADER_CC = 10;

}


#endif

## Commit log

2026-01-26 Initial commit
    add product requirements and references
    add help needed doc
    add join our discord badge
    fix typos
    describe references
    Add 'How does it work' section to README
    Added a section explaining the components of the FOSS DJ player.
    Enhance README with detailed component descriptions
    Updated component list with detailed notes for each part of the FOSS DJ player.
    Update hardware list and refine Linux Ricing description
    Added a new entry for 3D printed inserts in the hardware section and updated the Linux Ricing description.
    create diagrams doc
    include hardware diagram
    add hardware sketch
    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
2026-01-26 feat(pi-gen): setup pi-gen
    [config.txt, mixxx.cfg]
2026-02-25 feat(pi-gen): auto mount usb (#2)
    * feat(pi-gen): automount usb to /media/usb/(devname) with udev
    fix(pi-gen) use systemd-mount instead of mount
    * fixup! feat(pi-gen): automount usb to /media/usb/(devname) with udev
    * run chroot
    * fixup! run chroot
2026-02-28 chore(pi-gen): cleanup
    move one level below
    [mixxx.cfg]
2026-02-28 feat(pi-gen): seed mixxx config with XDJ100SX
    [mixxx.cfg]
2026-02-28 feat(pi-gen): disable other libraries than rekordbox
    [mixxx.cfg]
2026-02-28 chore: add release-it
    Revert "chore: add release-it"
    This reverts commit 4b5ca5531f152f0e18e43450eea5ec502a95fd4b.
    [pnpm-lock.yaml]
2026-03-15 feat(design): export cad files and measurements for pi5, cooler, lcd and dac
    [f16-2.dwg, f16-2.stp]
2026-03-21 feat(pi-gen): print ascii art in terminal (#18)
2026-03-23 fixup! docs: add og image generation
    [pnpm-lock.yaml]
2026-04-06 chore: move pi-gen to rpi/debian
    [config.txt, mixxx.cfg]
2026-04-16 feat(design): export obj files from autodesk (#24)
    [7inch_HDMI_LCD.obj]
2026-04-18 feat(alpine): create alpine based rpi image (#23)
    * create alpine folder
    * build alpine rootfs with docker
    * install aarch64 pacakages and linux-rpi kernel
    * setup system, user and desktop with alpine-conf
    * use zsh for pi user
    * extract rootfs in deploy folder
    * add raspberrypi-bootloader package
    * rename folder to rootfs
    * create disk img
    * change dir names and files
    * create skel dir
    * add usercfg.txt
    * create deploy dir if does not exist
    * print build commands
    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
    [pnpm-lock.yaml]
2026-05-17 chore: rename cad asset files
    [7inch_HDMI_LCD.obj, dac.obj, display.obj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]
2026-06-06 add teensy test folder
    git ignore
2026-06-18 feat(design): add prototype cad files (#31)
    [buttons+enclosures.obj, lcd_panel.obj, pi_dac.obj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]
2026-06-30 feat(design): modify foss-dj-player Grasshopper prototype (#32)
    * feat(design): add prototype cad files
    * Update Grasshopper prototype
    * Update Grasshopper prototype
    ---------
    [7inch_HDMI_LCD.obj, buttons+enclosures.obj, chassis.obj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]
2026-06-30 feat(firmware): initial draft (#30)
    * adding firmware dir for platformio.
    * add sensor list
    * updating sensor links
    * minor fix
    * adding config.h to define pins and midi chans. added buttons read in main
    * adding fader processing
    * updating readme
    * feat(firmware): adding browse encoder support
    * fix(firmware): bug fix in compiling
    * fix: removing pin 14 as it's A0
    * bug fixes
    * added jogwheel encoder (to be tested)
    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
    [config.h, main.cpp]
2026-07-06 docs: add bill of materials (#33)
    * docs: add bill of materials
    * chore: pin node and pnpm version
    * docs: add maintainers doc
